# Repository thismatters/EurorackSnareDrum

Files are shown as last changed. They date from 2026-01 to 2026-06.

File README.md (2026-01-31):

# Snare Drum

The circuit here is an implementation the circuit in the [Moritz Klien snare drum video](https://www.youtube.com/watch?v=hULEn2_4Unw) with all the trappings to make it a proper module. I recommend that video completely, please watch it. The circuit has 5 knobs, but I've limited myself to 4 knobs: Decay, Attack, Tone, and Pitch. The other knob is present as a screw-turn potentiometers accessible from the front panel for tuning Snappy.

The KiCAD project here uses the library/footprints [found in my companion repo](https://github.com/thismatters/EurorackKiCAD).

## Width

6hp on a standard 3U rack.

## Inputs

4 Jacks
- Gate
- Accent CV
- Snappy CV
- Pitch CV

4 Knobs:
- Decay
- Attack
- Tone
- Pitch

1 Screw Pot (accessible from front):
- Snappy

## Outputs

1 Jack for audio output.

## Vendors

There are part numbers in the [BOM](snare-drum.csv) for many of the parts (not for basic passives though) at the following vendors:

* [Mouser](https://www.mouser.com): Needs no introduction. Get your ICs from here (or [digikey](https://www.digikey.com)).
* [Tayda Electronics](https://www.taydaelectronics.com/): Good supplier for passive components; audio jacks, and potentiometers. Their audio jacks are slightly smaller than the thonkiconn from thonk.
* [Love My Switches](https://lovemyswitches.com/): Has [really good knobs](https://lovemyswitches.com/anodized-aluminum-knob-the-lo-fi-1-4-smooth-shaft-12-5mm-od/) to go on those potentiometers!
* [OSHPark](https://oshpark.com/): Fast and (relatively) cheap PCB manufacturer. Prototype run pending.

## Changelog

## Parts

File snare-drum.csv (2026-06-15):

Reference | Qty | Value | Footprint | Vendor | PartNum | #
C1,C2 | 2 | 22u 50V | Capacitor_THT:CP_Radial_D5.0mm_P2.50mm |  |  | 1
C3,C4 | 2 | 100n | Capacitor_SMD:C_0805_2012Metric |  |  | 2
C5,C15 | 2 | 10n | Capacitor_SMD:C_0805_2012Metric |  |  | 3
C6,C7,C10 | 3 | 33n | Capacitor_SMD:C_0805_2012Metric |  |  | 4
C8,C16 | 2 | 470n | Capacitor_SMD:C_0805_2012Metric |  |  | 5
C9 | 1 | 1u box | Capacitor_THT:C_Rect_L7.2mm_W7.2mm_P5.00mm_FKS2_FKP2_MKS2_MKP2 |  |  | 6
C11,C12 | 2 | 2.2n | Capacitor_SMD:C_0805_2012Metric |  |  | 7
C13,C14 | 2 | 1n | Capacitor_SMD:C_0805_2012Metric |  |  | 8
D1,D2 | 2 | BAT54S | Package_TO_SOT_SMD:SOT-23 | Mouser | 863-BAT54SLT1G | 9
D3,D4,D5,D6,D7,D8,D9 | 7 | 1N4148 | Diode_SMD:D_SOD-323_HandSoldering |  |  | 10
J1 | 1 | Conn_02x05_Odd_Even | Eurorack:PinHeader_2x05_P2.54mm_Vertical | Tayda | A-2939 | 11
J2 | 1 | GATE | Eurorack:AudioJack2_Tayda_A-2566 | Tayda | A-2566 | 12
J3 | 1 | ACCENT_CV | Eurorack:AudioJack2_Tayda_A-2566 | Tayda | A-2566 | 13
J4 | 1 | PITCH_CV | Eurorack:AudioJack2_Tayda_A-2566 | Tayda | A-2566 | 14
J5 | 1 | SNAPPY_CV | Eurorack:AudioJack2_Tayda_A-2566 | Tayda | A-2566 | 15
J6 | 1 | OUT | Eurorack:AudioJack2_Tayda_A-2566 | Tayda | A-2566 | 16
Q1 | 1 | BCM857 | Package_SO:TSOP-6_1.65x3.05mm_P0.95mm | Mouser | 771-BCM857DS135 | 17
Q2,Q4 | 2 | BCM847 | Package_SO:TSOP-6_1.65x3.05mm_P0.95mm | Mouser | 771-BCM847DS135 | 18
Q3 | 1 | BC547C | Package_TO_SOT_THT:TO-92_Inline_Wide |  |  | 19
R1,R2 | 2 | 10 | Resistor_SMD:R_0805_2012Metric |  |  | 20
R3 | 1 | 39K | Resistor_SMD:R_0805_2012Metric |  |  | 21
R4,R31 | 2 | 33K | Resistor_SMD:R_0805_2012Metric |  |  | 22
R5,R6,R20,R21,R22,R26 | 6 | 100K | Resistor_SMD:R_0805_2012Metric |  |  | 23
R7,R23,R27,R28,R29 | 5 | 22K | Resistor_SMD:R_0805_2012Metric |  |  | 24
R8 | 1 | 120K | Resistor_SMD:R_0805_2012Metric |  |  | 25
R9,R30,R33,R34,R35 | 5 | 10K | Resistor_SMD:R_0805_2012Metric |  |  | 26
R10,R19,R32 | 3 | 1K | Resistor_SMD:R_0805_2012Metric |  |  | 27
R11 | 1 | 910K | Resistor_SMD:R_0805_2012Metric |  |  | 28
R12 | 1 | 330 | Resistor_SMD:R_0805_2012Metric |  |  | 29
R13 | 1 | 470 | Resistor_SMD:R_0805_2012Metric |  |  | 30
R14,R15,R17 | 3 | 47K | Resistor_SMD:R_0805_2012Metric |  |  | 31
R16 | 1 | 470K | Resistor_SMD:R_0805_2012Metric |  |  | 32
R18 | 1 | 27K | Resistor_SMD:R_0805_2012Metric |  |  | 33
R24,R25 | 2 | 1M | Resistor_SMD:R_0805_2012Metric |  |  | 34
RV1 | 1 | B1K | Eurorack:Potentiometer_RV16AF-41-15R1 |  |  | 35
RV2,RV5 | 2 | B100K | Eurorack:Potentiometer_RV16AF-41-15R1 |  |  | 36
RV3 | 1 | B5K | Eurorack:Potentiometer_RV16AF-41-15R1 |  |  | 37
RV4 | 1 | 100K | Potentiometer_THT:Potentiometer_Bourns_3296W_Vertical |  |  | 38
U1 | 1 | TL072 | Package_SO:SOIC-8_3.9x4.9mm_P1.27mm | Mouser | 595-TL072CDR | 39
U2 | 1 | TL074 | Package_SO:SO-14_3.9x8.65mm_P1.27mm | Mouser | 595-TL074CDR | 40

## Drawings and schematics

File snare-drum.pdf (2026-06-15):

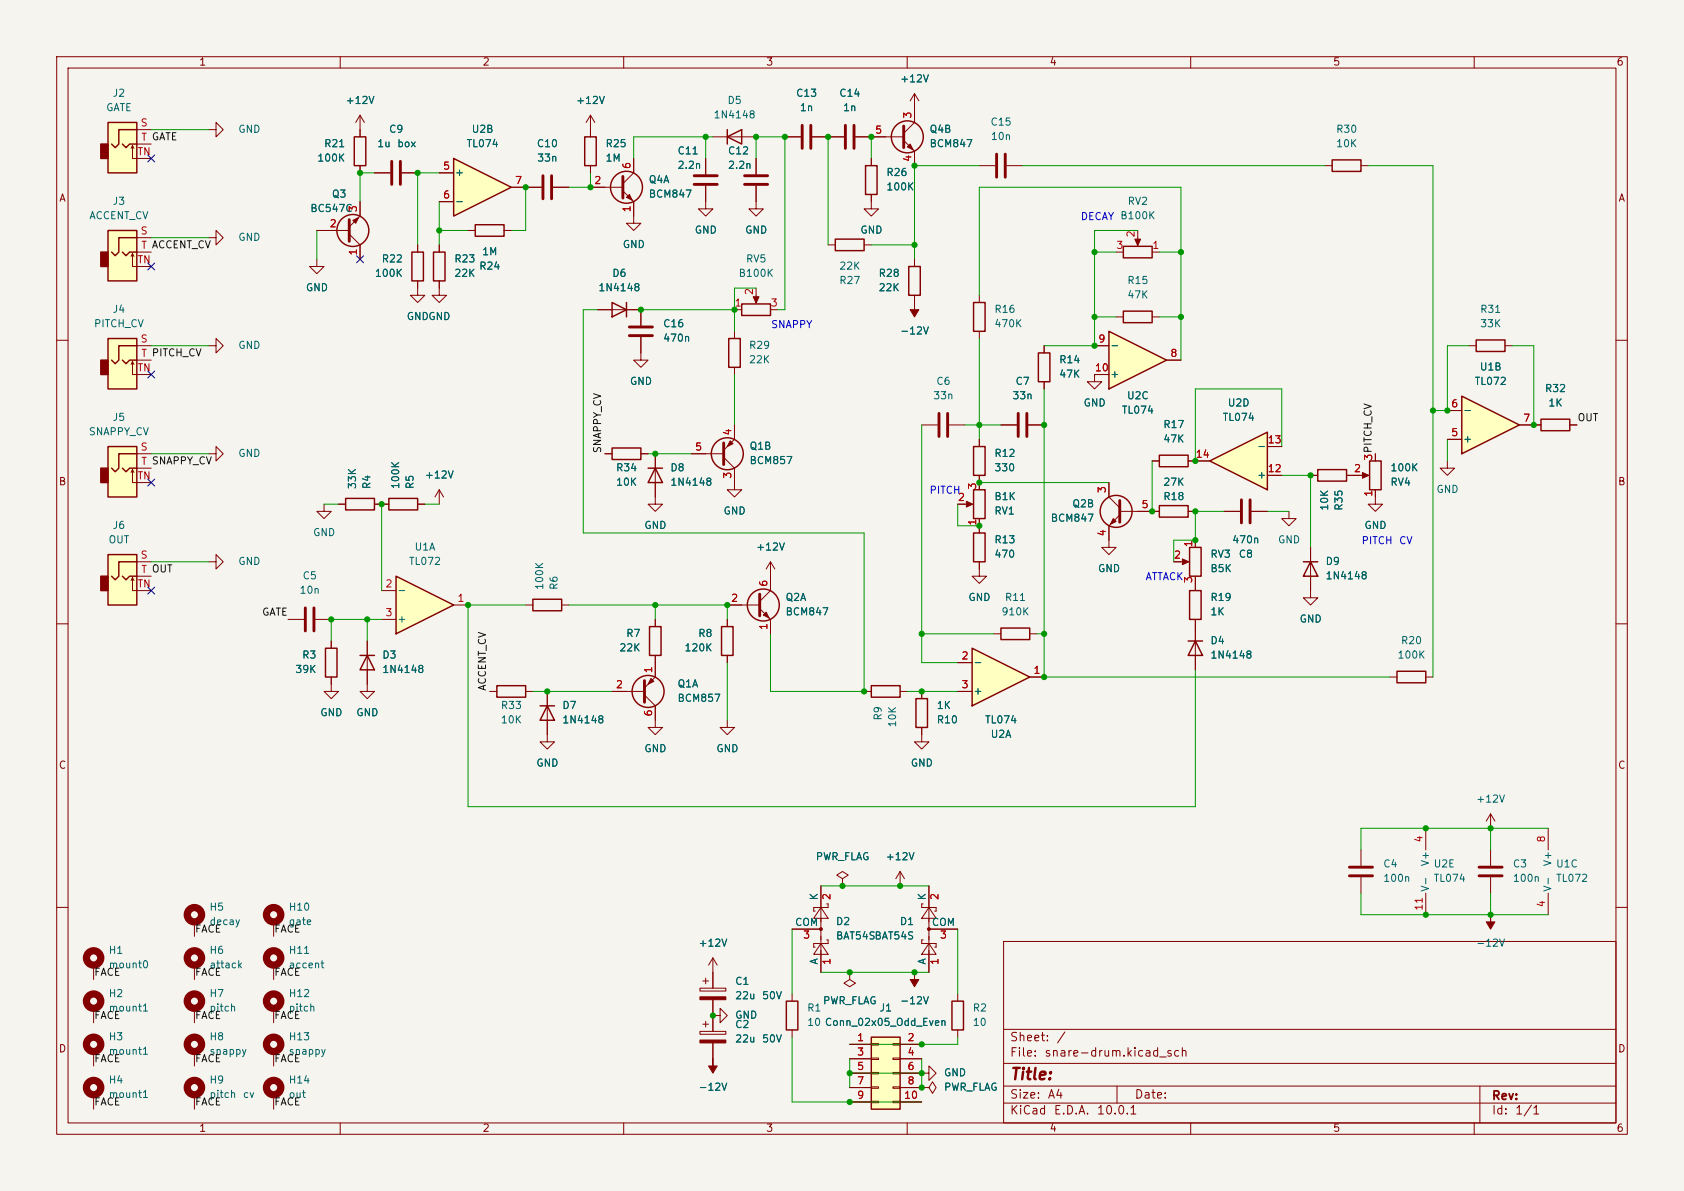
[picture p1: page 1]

5 5 | 6 6
7 7 | 8 8

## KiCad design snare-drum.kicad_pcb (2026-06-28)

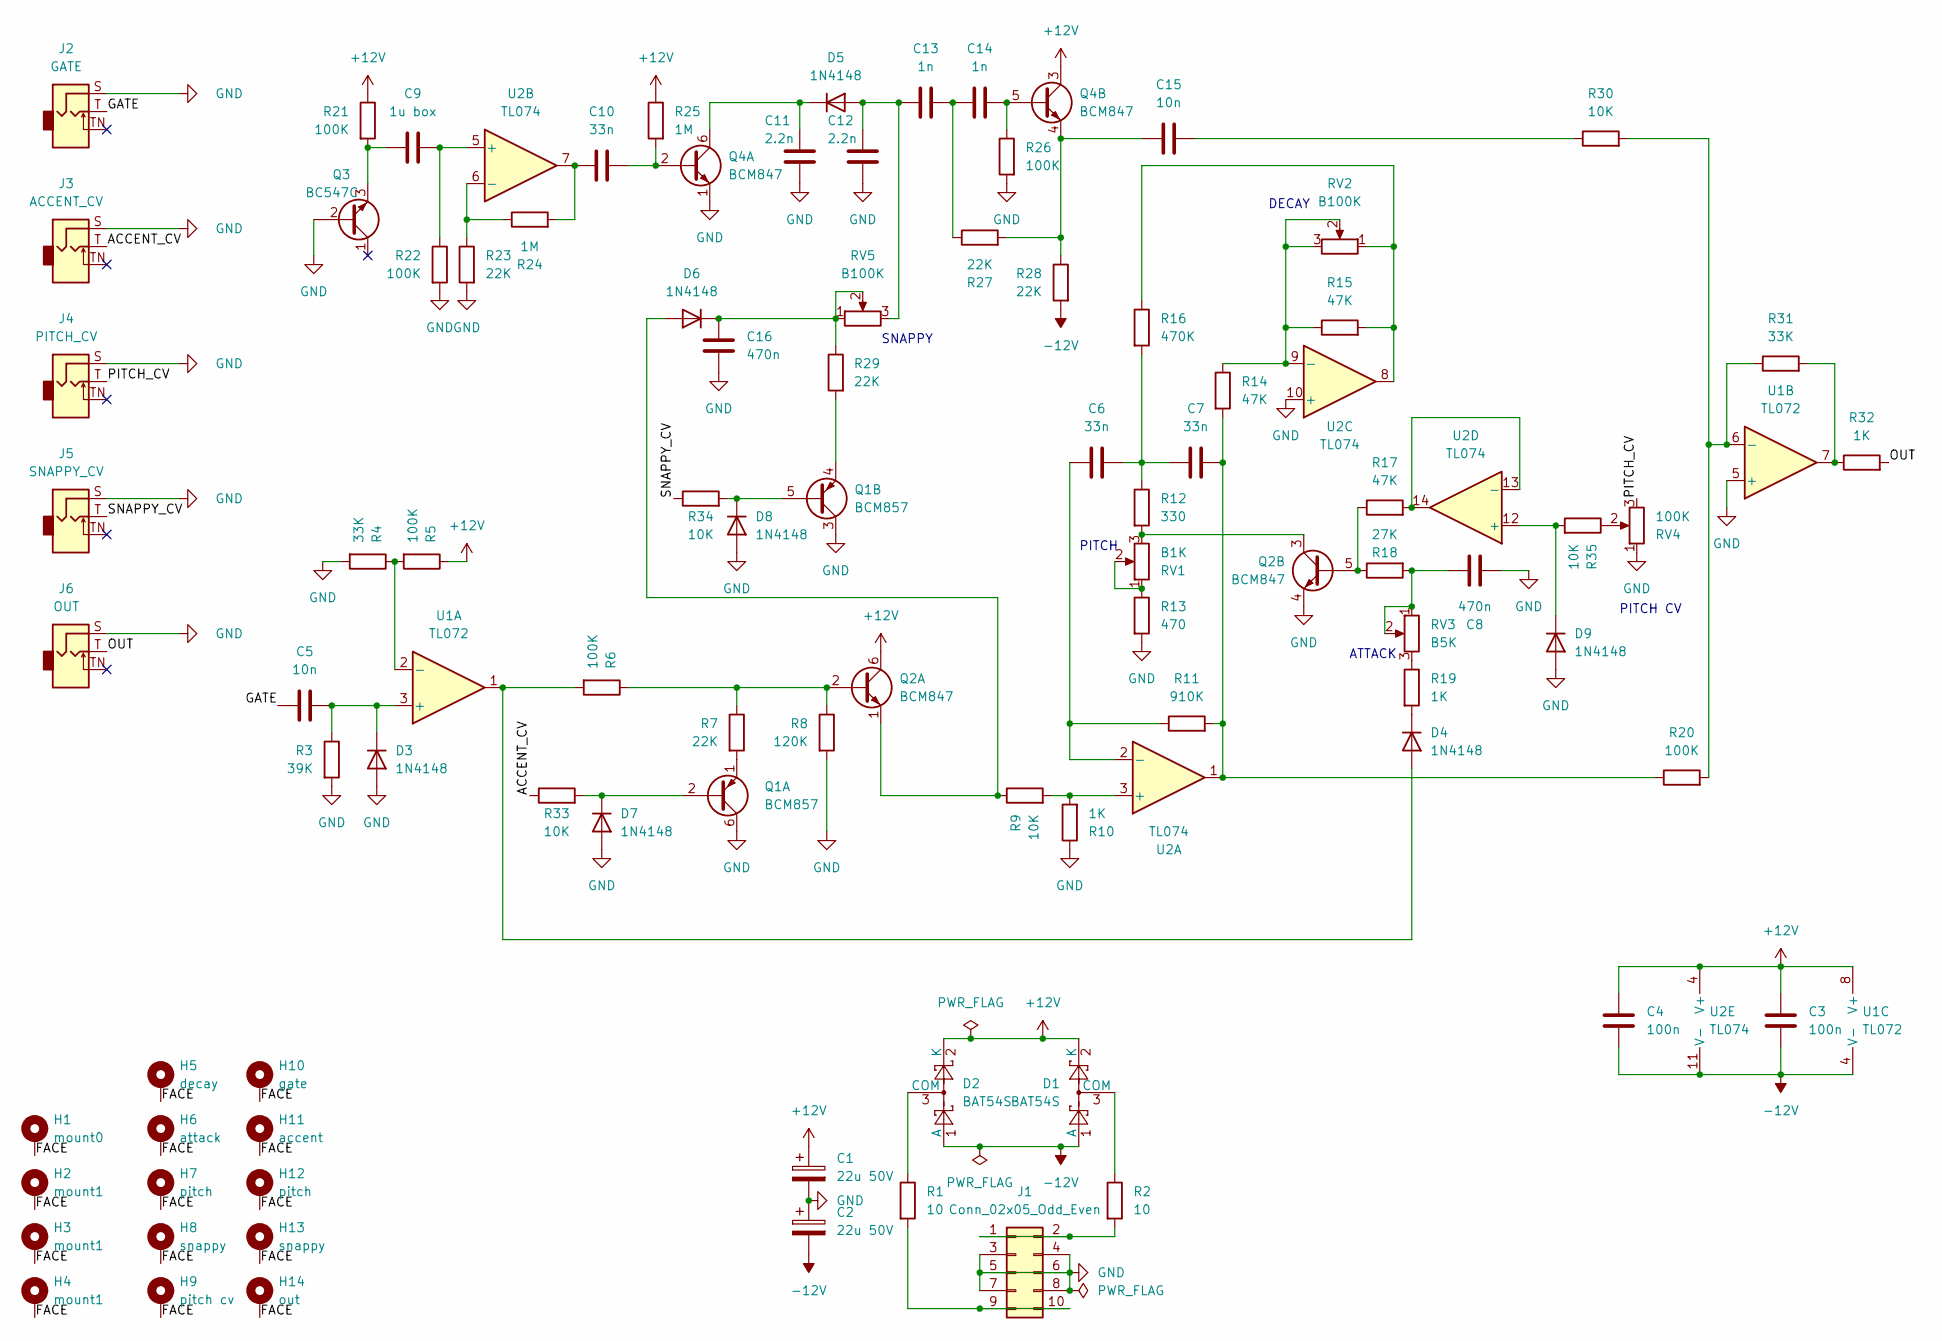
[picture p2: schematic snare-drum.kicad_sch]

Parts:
C1, C2: 22u 50V; CP_Radial_D5.0mm_P2.50mm
C3, C4: 100n; C_0805_2012Metric
C5, C15: 10n; C_0805_2012Metric
C6, C7, C10: 33n; C_0805_2012Metric
C8, C16: 470n; C_0805_2012Metric
C9: 1u box; C_Rect_L7.2mm_W7.2mm_P5.00mm_FKS2_FKP2_MKS2_MKP2
C11, C12: 2.2n; C_0805_2012Metric
C13, C14: 1n; C_0805_2012Metric
D1, D2: BAT54S; SOT-23; PartNum 863-BAT54SLT1G
D3, D4, D5, D6, D7, D8, D9: 1N4148; D_SOD-323_HandSoldering
H1: mount0; Mech-MountingHole
H2, H3, H4: mount1; Mech-MountingHole
H5: decay; Mech-Potentiometer-Hole_level
H6: attack; Mech-Potentiometer-Hole_level
H7: pitch; Mech-Potentiometer-Hole_level
H8: snappy; Mech-Potentiometer-Hole_level
H9: pitch cv; Mech-LED-Hole-3mm
H10: gate; Mech-AudioJack-Hole-Input-Gate
H11: accent; Mech-AudioJack-Hole-Input-CV
H12: pitch; Mech-AudioJack-Hole-Input-CV
H13: snappy; Mech-AudioJack-Hole-Input-CV
H14: out; Mech-AudioJack-Hole-Output
J1: Conn_02x05_Odd_Even; PinHeader_2x05_P2.54mm_Vertical; PartNum A-2939
J2: GATE; AudioJack2_Tayda_A-2566; PartNum A-2566
J3: ACCENT_CV; AudioJack2_Tayda_A-2566; PartNum A-2566
J4: PITCH_CV; AudioJack2_Tayda_A-2566; PartNum A-2566
J5: SNAPPY_CV; AudioJack2_Tayda_A-2566; PartNum A-2566
J6: OUT; AudioJack2_Tayda_A-2566; PartNum A-2566
Q1: BCM857; TSOP-6_1.65x3.05mm_P0.95mm; PartNum 771-BCM857DS135
Q2, Q4: BCM847; TSOP-6_1.65x3.05mm_P0.95mm; PartNum 771-BCM847DS135
Q3: BC547C; TO-92_Inline_Wide
R1, R2: 10; R_0805_2012Metric
R3: 39K; R_0805_2012Metric
R4, R31: 33K; R_0805_2012Metric
R5, R6, R20, R21, R22, R26: 100K; R_0805_2012Metric
R7, R23, R27, R28, R29: 22K; R_0805_2012Metric
R8: 120K; R_0805_2012Metric
R9, R30, R33, R34, R35: 10K; R_0805_2012Metric
R10, R19, R32: 1K; R_0805_2012Metric
R11: 910K; R_0805_2012Metric
R12: 330; R_0805_2012Metric
R13: 470; R_0805_2012Metric
R14, R15, R17: 47K; R_0805_2012Metric
R16: 470K; R_0805_2012Metric
R18: 27K; R_0805_2012Metric
R24, R25: 1M; R_0805_2012Metric
RV1: B1K; Potentiometer_RV16AF-41-15R1
RV2, RV5: B100K; Potentiometer_RV16AF-41-15R1
RV3: B5K; Potentiometer_RV16AF-41-15R1
RV4: 100K; Potentiometer_Bourns_3296W_Vertical
U1: TL072; SOIC-8_3.9x4.9mm_P1.27mm; PartNum 595-TL072CDR
U2: TL074; SO-14_3.9x8.65mm_P1.27mm; PartNum 595-TL074CDR

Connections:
+12V: C1.1, C3.1, C4.1, D1.2 (K), D2.2 (K), Q2.6 (C1), Q4.3 (C2), R5.1, R21.1, R25.1, U1.8 (V+), U2.4 (V+)
-12V: C2.2, C3.2, C4.2, D1.1 (A), D2.1 (A), R28.2, U1.4 (V-), U2.11 (V-)
/ACCENT_CV: J3.T, R33.1
/FACE: H1.1 (1_1), H2.1 (1_1), H3.1 (1_1), H4.1 (1_1), H5.1 (1_1), H6.1 (1_1), H7.1 (1_1), H8.1 (1_1), H9.1 (1_1), H10.1 (1_1), H11.1 (1_1), H12.1 (1_1), H13.1 (1_1), H14.1 (1_1)
/GATE: C5.1, J2.T
/OUT: J6.T, R32.2
/PITCH_CV: J4.T, RV4.3
/SNAPPY_CV: J5.T, R34.1
GND: C1.2, C2.1, C8.2, C11.2, C12.2, C16.2, D3.2 (A), D7.2 (A), D8.2 (A), D9.2 (A), J1.3, J1.4, J1.5, J1.6, J1.7, J1.8, J2.S, J3.S, J4.S, J5.S, J6.S, Q1.3 (C2), Q1.6 (C1), Q2.4 (E2), Q3.2 (B), Q4.1 (E1), R3.2, R4.2, R8.2, R10.1, R13.2, R22.2, R23.2, R26.2, RV4.1, U1.5 (+), U2.10 (+)
unnamed: C6.2, C7.1, R12.1, R16.2
unnamed: C7.2, R11.2, R14.2, R20.1, U2.1
unnamed: C8.1, R18.2, RV3.1, RV3.2
unnamed: C10.1, R24.2, U2.7
unnamed: C13.2, C14.1, R27.1
unnamed: C15.2, R30.1
unnamed: D1.3 (COM), R2.1
unnamed: D2.3 (COM), R1.1
unnamed: C5.2, D3.1 (K), R3.1, U1.3 (+)
unnamed: D4.2 (A), R6.2, U1.1
unnamed: D4.1 (K), R19.2
unnamed: C12.1, C13.1, D5.2 (A), RV5.3
unnamed: C11.1, D5.1 (K), Q4.6 (C1)
unnamed: D6.2 (A), Q2.1 (E1), R9.1
unnamed: C16.1, D6.1 (K), R29.1, RV5.1, RV5.2
unnamed: D7.1 (K), Q1.2 (B1), R33.2
unnamed: D8.1 (K), Q1.5 (B2), R34.2
unnamed: D9.1 (K), R35.2, U2.12 (+)
unnamed: J1.1, J1.2, R2.2
unnamed: J1.9, J1.10, R1.2
unnamed: Q1.1 (E1), R7.2
unnamed: Q1.4 (E2), R29.2
unnamed: Q2.2 (B1), R6.1, R7.1, R8.1
unnamed: Q2.5 (B2), R17.1, R18.1
unnamed: Q2.3 (C2), R12.2, RV1.3
unnamed: C9.1, Q3.3 (E), R21.2
unnamed: C10.2, Q4.2 (B1), R25.2
unnamed: C14.2, Q4.5 (B2), R26.1
unnamed: C15.1, Q4.4 (E2), R27.2, R28.1
unnamed: R13.1, RV1.1, RV1.2
unnamed: R15.2, R16.1, RV2.1, U2.8
unnamed: R19.1, RV3.3
unnamed: R31.2, R32.1, U1.7
unnamed: R35.1, RV4.2
unnamed: R4.1, R5.2, U1.2 (-)
unnamed: R20.2, R30.2, R31.1, U1.6 (-)
unnamed: R9.2, R10.2, U2.3 (+)
unnamed: C6.1, R11.1, U2.2 (-)
unnamed: C9.2, R22.1, U2.5 (+)
unnamed: R23.1, R24.1, U2.6 (-)
unnamed: R14.1, R15.1, RV2.2, RV2.3, U2.9 (-)
unnamed: R17.2, U2.13 (-), U2.14

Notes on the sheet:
ATTACK
PITCH CV
PITCH
DECAY
SNAPPY

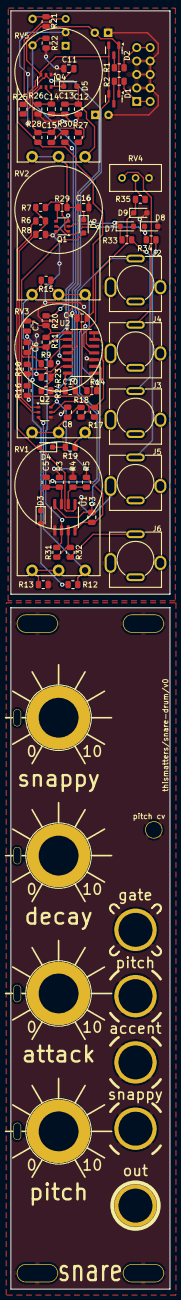
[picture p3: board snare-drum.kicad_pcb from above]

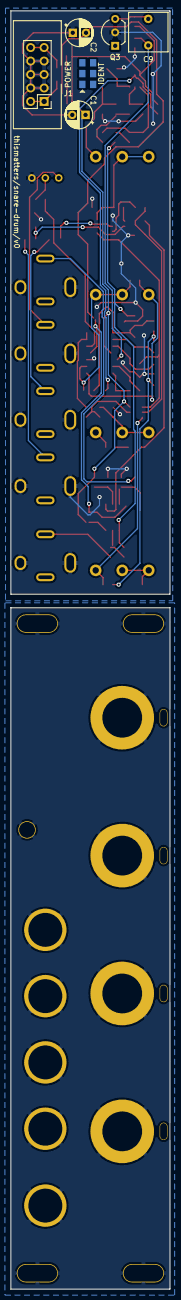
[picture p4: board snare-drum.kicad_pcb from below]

Board: 2 copper layers, 30.0 x 241.0 mm, 91 parts (5 on the bottom side), 51 nets.

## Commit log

2026-01-31 fix resistor values
    [snare-drum.csv, snare-drum.kicad_sch]
2026-02-01 adding protection to CV inputs
    [snare-drum.csv, snare-drum.kicad_sch]
2026-06-06 kicad 10, fixing bom
    [snare-drum.csv, snare-drum.kicad_sch]
2026-06-15 v0 ready
    [snare-drum.csv, snare-drum.kicad_pcb, snare-drum.kicad_sch]
2026-06-28 add ident
    [snare-drum.kicad_pcb]
